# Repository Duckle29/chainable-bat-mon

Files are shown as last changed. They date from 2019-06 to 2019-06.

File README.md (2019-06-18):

# chainable-bat-mon
A daisy chainable battery monitor

This is a battery monitor meant to monitor lead acid batteries. If the battery voltage goes below a configurable set point, 
set by the potentiometer, the LED will turn on, and the optocoupler will pull the output line on the TRS connectors low.

To use the signal, supply 5v and gnd on the tip and sleeve of a 3.5mm mini-jack cable, and solder the jumper on one of the PCBs. Then just chain them together.
If the battery voltage goes low on any of the batteries, the signal line will go low.

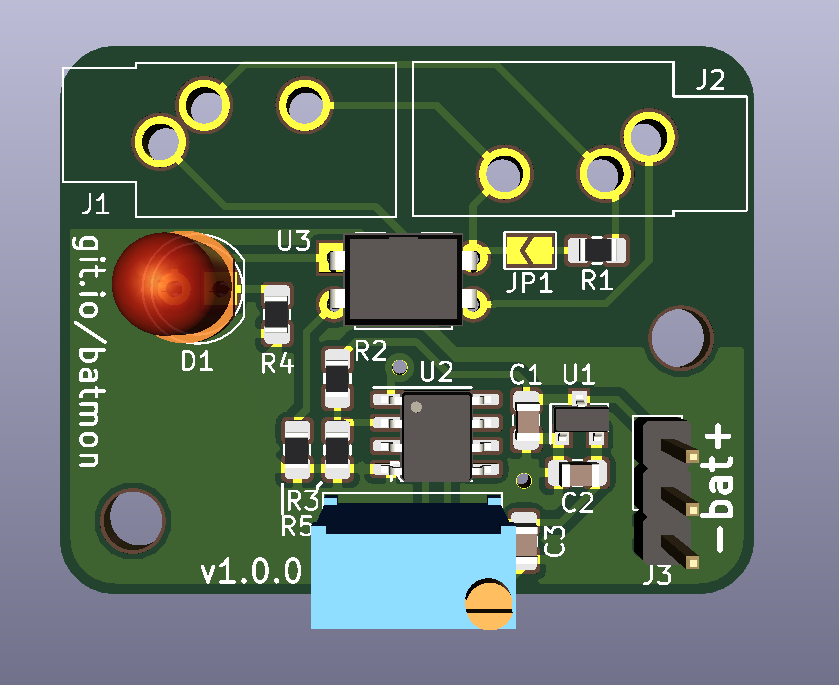
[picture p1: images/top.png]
toprender

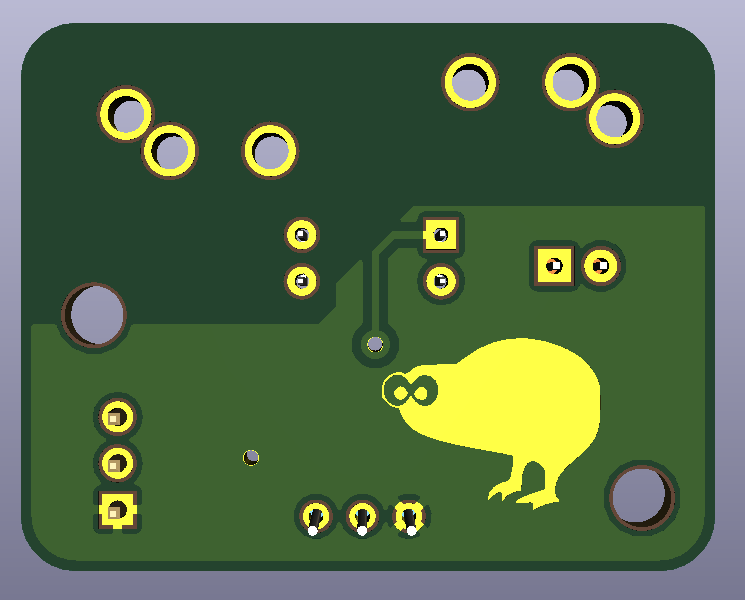
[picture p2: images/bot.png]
botrender


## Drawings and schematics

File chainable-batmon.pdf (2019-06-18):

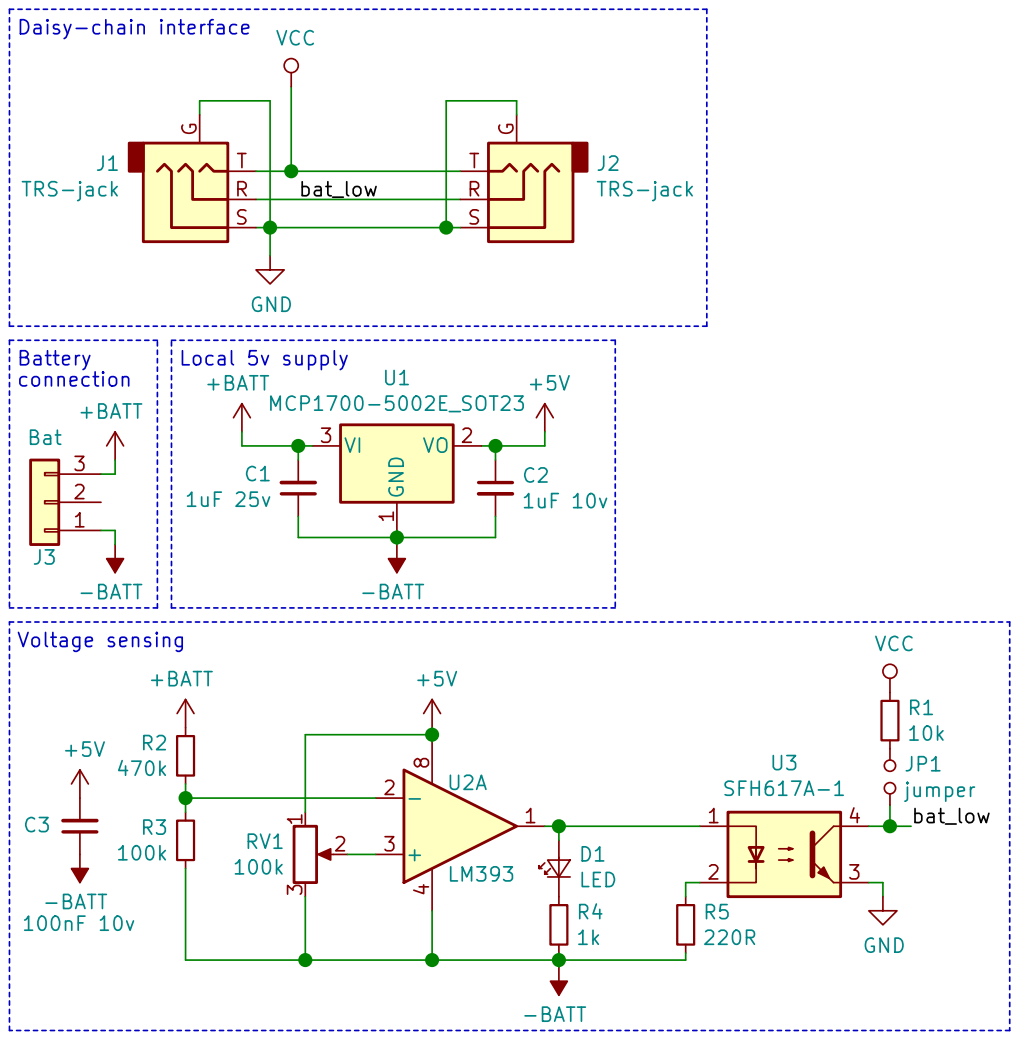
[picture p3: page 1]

Id: 1/1 Title: File: chainable-batmon.sch Sheet: / V- 4 V+

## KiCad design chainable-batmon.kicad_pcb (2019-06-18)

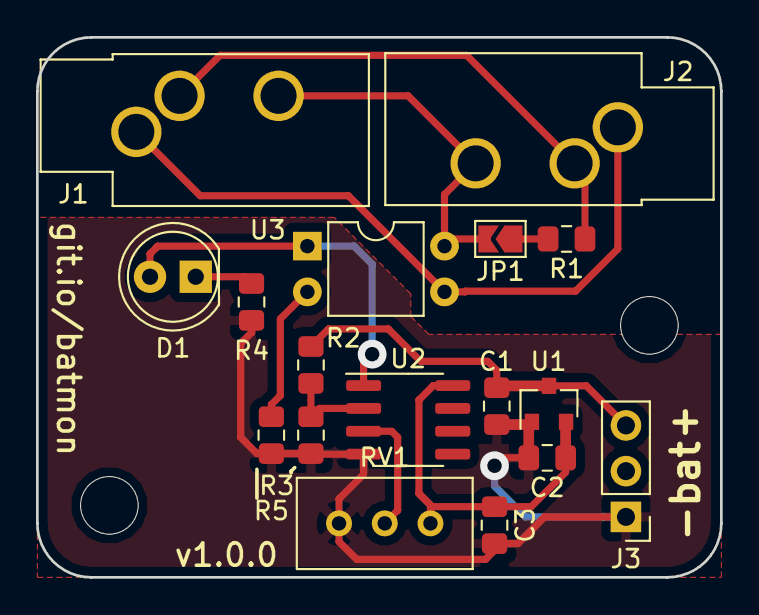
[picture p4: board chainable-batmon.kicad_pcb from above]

Board: 2 copper layers, 38.0 x 30.0 mm, 17 parts (0 on the bottom side), 12 nets.

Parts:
C1: 1uF 25v; C_0805_2012Metric_Pad1.15x1.40mm_HandSolder
C2: 1uF 10v; C_0805_2012Metric_Pad1.15x1.40mm_HandSolder
C3: 100nF 10v; C_0805_2012Metric_Pad1.15x1.40mm_HandSolder
D1: LED; LED_D5.0mm
J1, J2: TRS-jack; Jack_3.5mm_CUI_SJ1-3533NG_Horizontal_CircularHoles
J3: Bat; PinHeader_1x03_P2.54mm_Vertical
JP1: jumper; SolderJumper-2_P1.3mm_Open_TrianglePad1.0x1.5mm
R1: 10k; R_0805_2012Metric_Pad1.15x1.40mm_HandSolder
R2: 470k; R_0805_2012Metric_Pad1.15x1.40mm_HandSolder
R3: 100k; R_0805_2012Metric_Pad1.15x1.40mm_HandSolder
R4: 1k; R_0805_2012Metric_Pad1.15x1.40mm_HandSolder
R5: 220R; R_0805_2012Metric_Pad1.15x1.40mm_HandSolder
RV1: 100k; Potentiometer_Bourns_3296W_Vertical
U1: MCP1700-5002E_SOT23; SOT-23
U2: LM393; SOIC-8_3.9x4.9mm_P1.27mm
U3: SFH617A-1; DIP-4_W7.62mm

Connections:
+5V: C2.1, C3.2, RV1.1, U1.2, U2.8
+BATT: C1.2, J3.3, R2.1, U1.3
-BATT: C1.1, C2.2, C3.1, J3.1, R3.2, R4.2, R5.2, RV1.3, U1.1, U2.4
/bat_low: J1.R, J2.R, JP1.2, U3.4
GND: J1.S, J2.S, U3.3
unnamed: D1.1, R4.1
unnamed: D1.2, U2.1, U3.1
unnamed: JP1.1, R1.2
unnamed: R2.2, R3.1, U2.2
unnamed: R5.1, U3.2
unnamed: RV1.2, U2.3
VCC: J1.T, J2.T, R1.1

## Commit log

2019-06-18 Added renders and updated readme
    [chainable-batmon.kicad_pcb]
2019-06-18 Added schematic pdf
